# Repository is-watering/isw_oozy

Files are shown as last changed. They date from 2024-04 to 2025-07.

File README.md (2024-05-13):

# ISW-OOZY
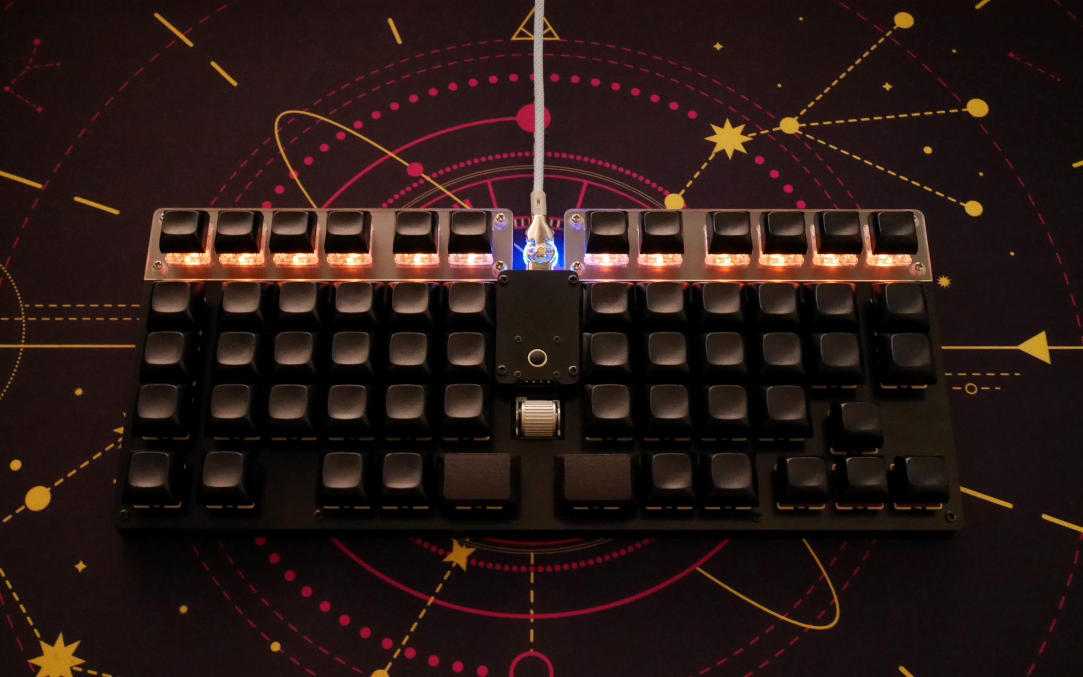
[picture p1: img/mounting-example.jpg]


ISW-OOZY is an orthoish keyboard with offset clusters.

[Build guide](doc/buildguide.md)

## Dependencies (KiCad)
* [is-watering/isw-kbd-lib](https://github.com/is-watering/isw-kbd-lib)
* [Salicylic-acid3/KiCAD_FootPrint](https://github.com/Salicylic-acid3/KiCAD_FootPrint)
* [koktoh/BrownSugar_KBD_KiCad_Library](https://github.com/koktoh/BrownSugar_KBD_KiCad_Library)

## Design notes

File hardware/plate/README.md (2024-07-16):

## Recommended format
Name                        |Material |Thickness      |Notes
----------------------------|---------|---------------|-----
Switch plate A              |-        |1.6mm or 2.0mm |
Switch plate B              |-        |1.6mm or 2.0mm |
Bottom plate                |-        |1.2mm - 2.0mm  |
Cover plate for AZ1UBALL    |FR4      |1.0mm - 1.2mm  |
Cover plate for StickPointV |-        |1.6mm or 2.0mm |

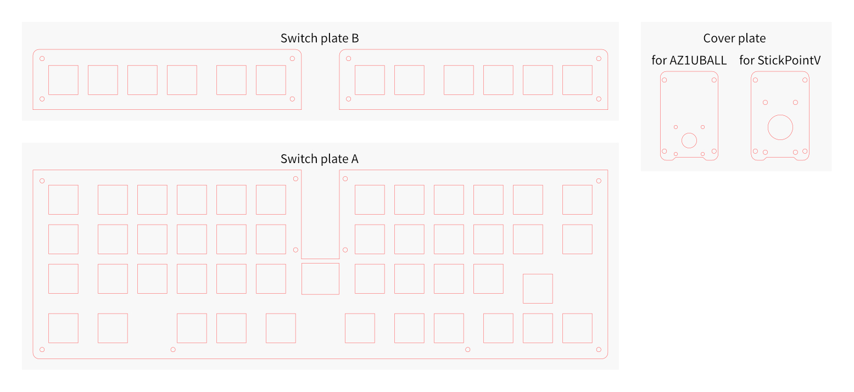
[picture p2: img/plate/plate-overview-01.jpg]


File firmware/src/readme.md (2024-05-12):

# isw_oozy

isw_oozy

*A short description of the keyboard/project*

* Keyboard Maintainer: [is_watering](https://github.com/is_watering)
* Hardware Supported: *The PCBs, controllers supported*
* Hardware Availability: *Links to where you can find this hardware*

Make example for this keyboard (after setting up your build environment):

    make isw_oozy:default

Flashing example for this keyboard:

    make isw_oozy:default:flash

See the [build environment setup](https://docs.qmk.fm/#/getting_started_build_tools) and the [make instructions](https://docs.qmk.fm/#/getting_started_make_guide) for more information. Brand new to QMK? Start with our [Complete Newbs Guide](https://docs.qmk.fm/#/newbs).

## Bootloader

Enter the bootloader in 3 ways:

* **Bootmagic reset**: Hold down the key at (0,0) in the matrix (usually the top left key or Escape) and plug in the keyboard
* **Physical reset button**: Briefly press the button on the back of the PCB - some may have pads you must short instead
* **Keycode in layout**: Press the key mapped to `QK_BOOT` if it is available

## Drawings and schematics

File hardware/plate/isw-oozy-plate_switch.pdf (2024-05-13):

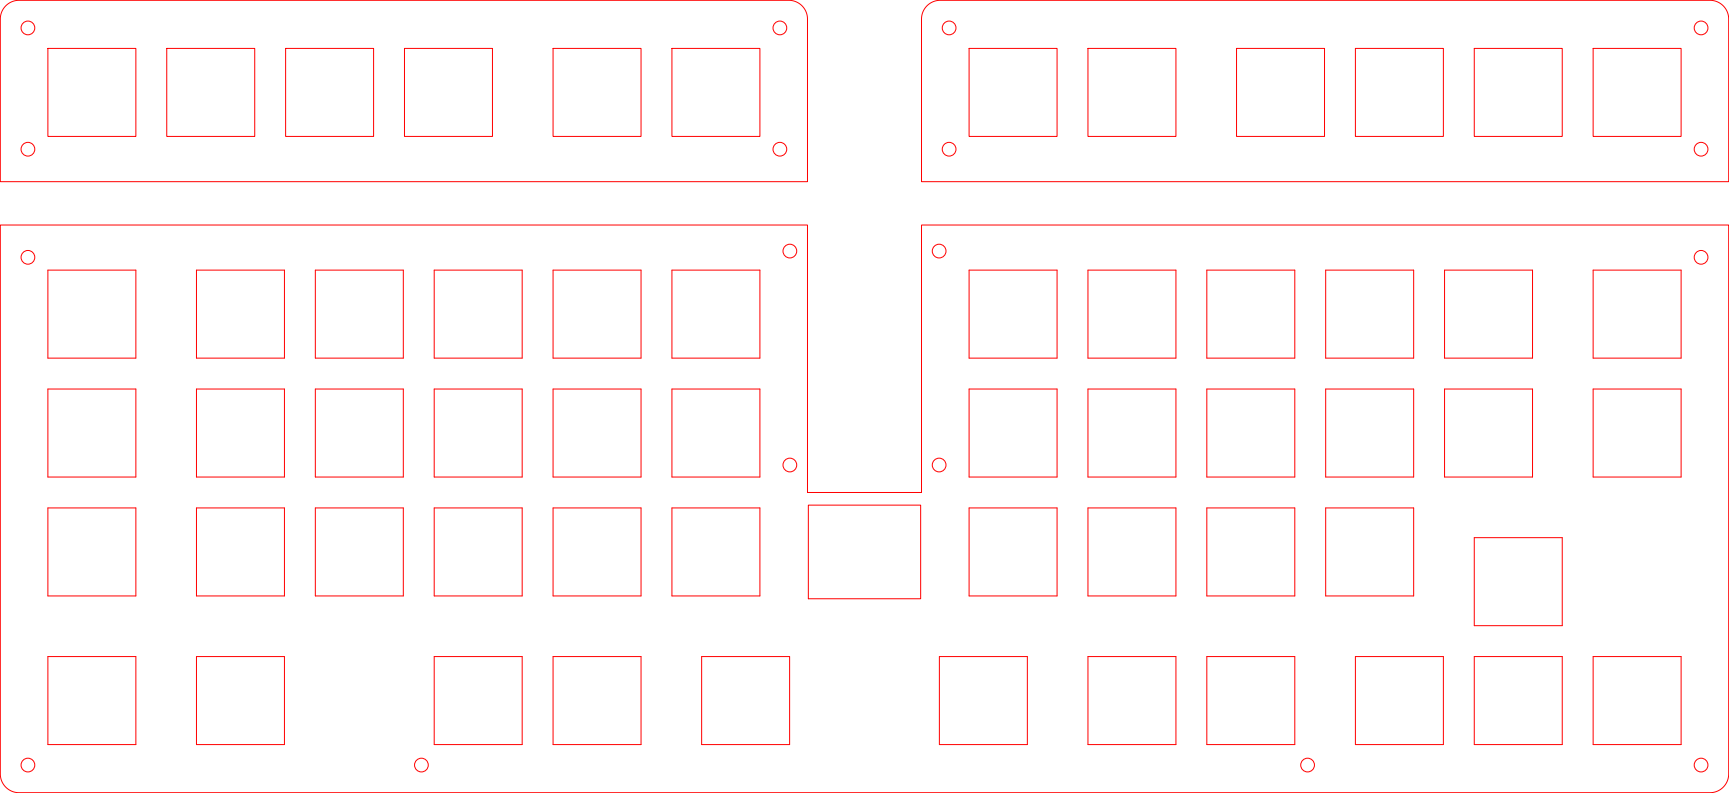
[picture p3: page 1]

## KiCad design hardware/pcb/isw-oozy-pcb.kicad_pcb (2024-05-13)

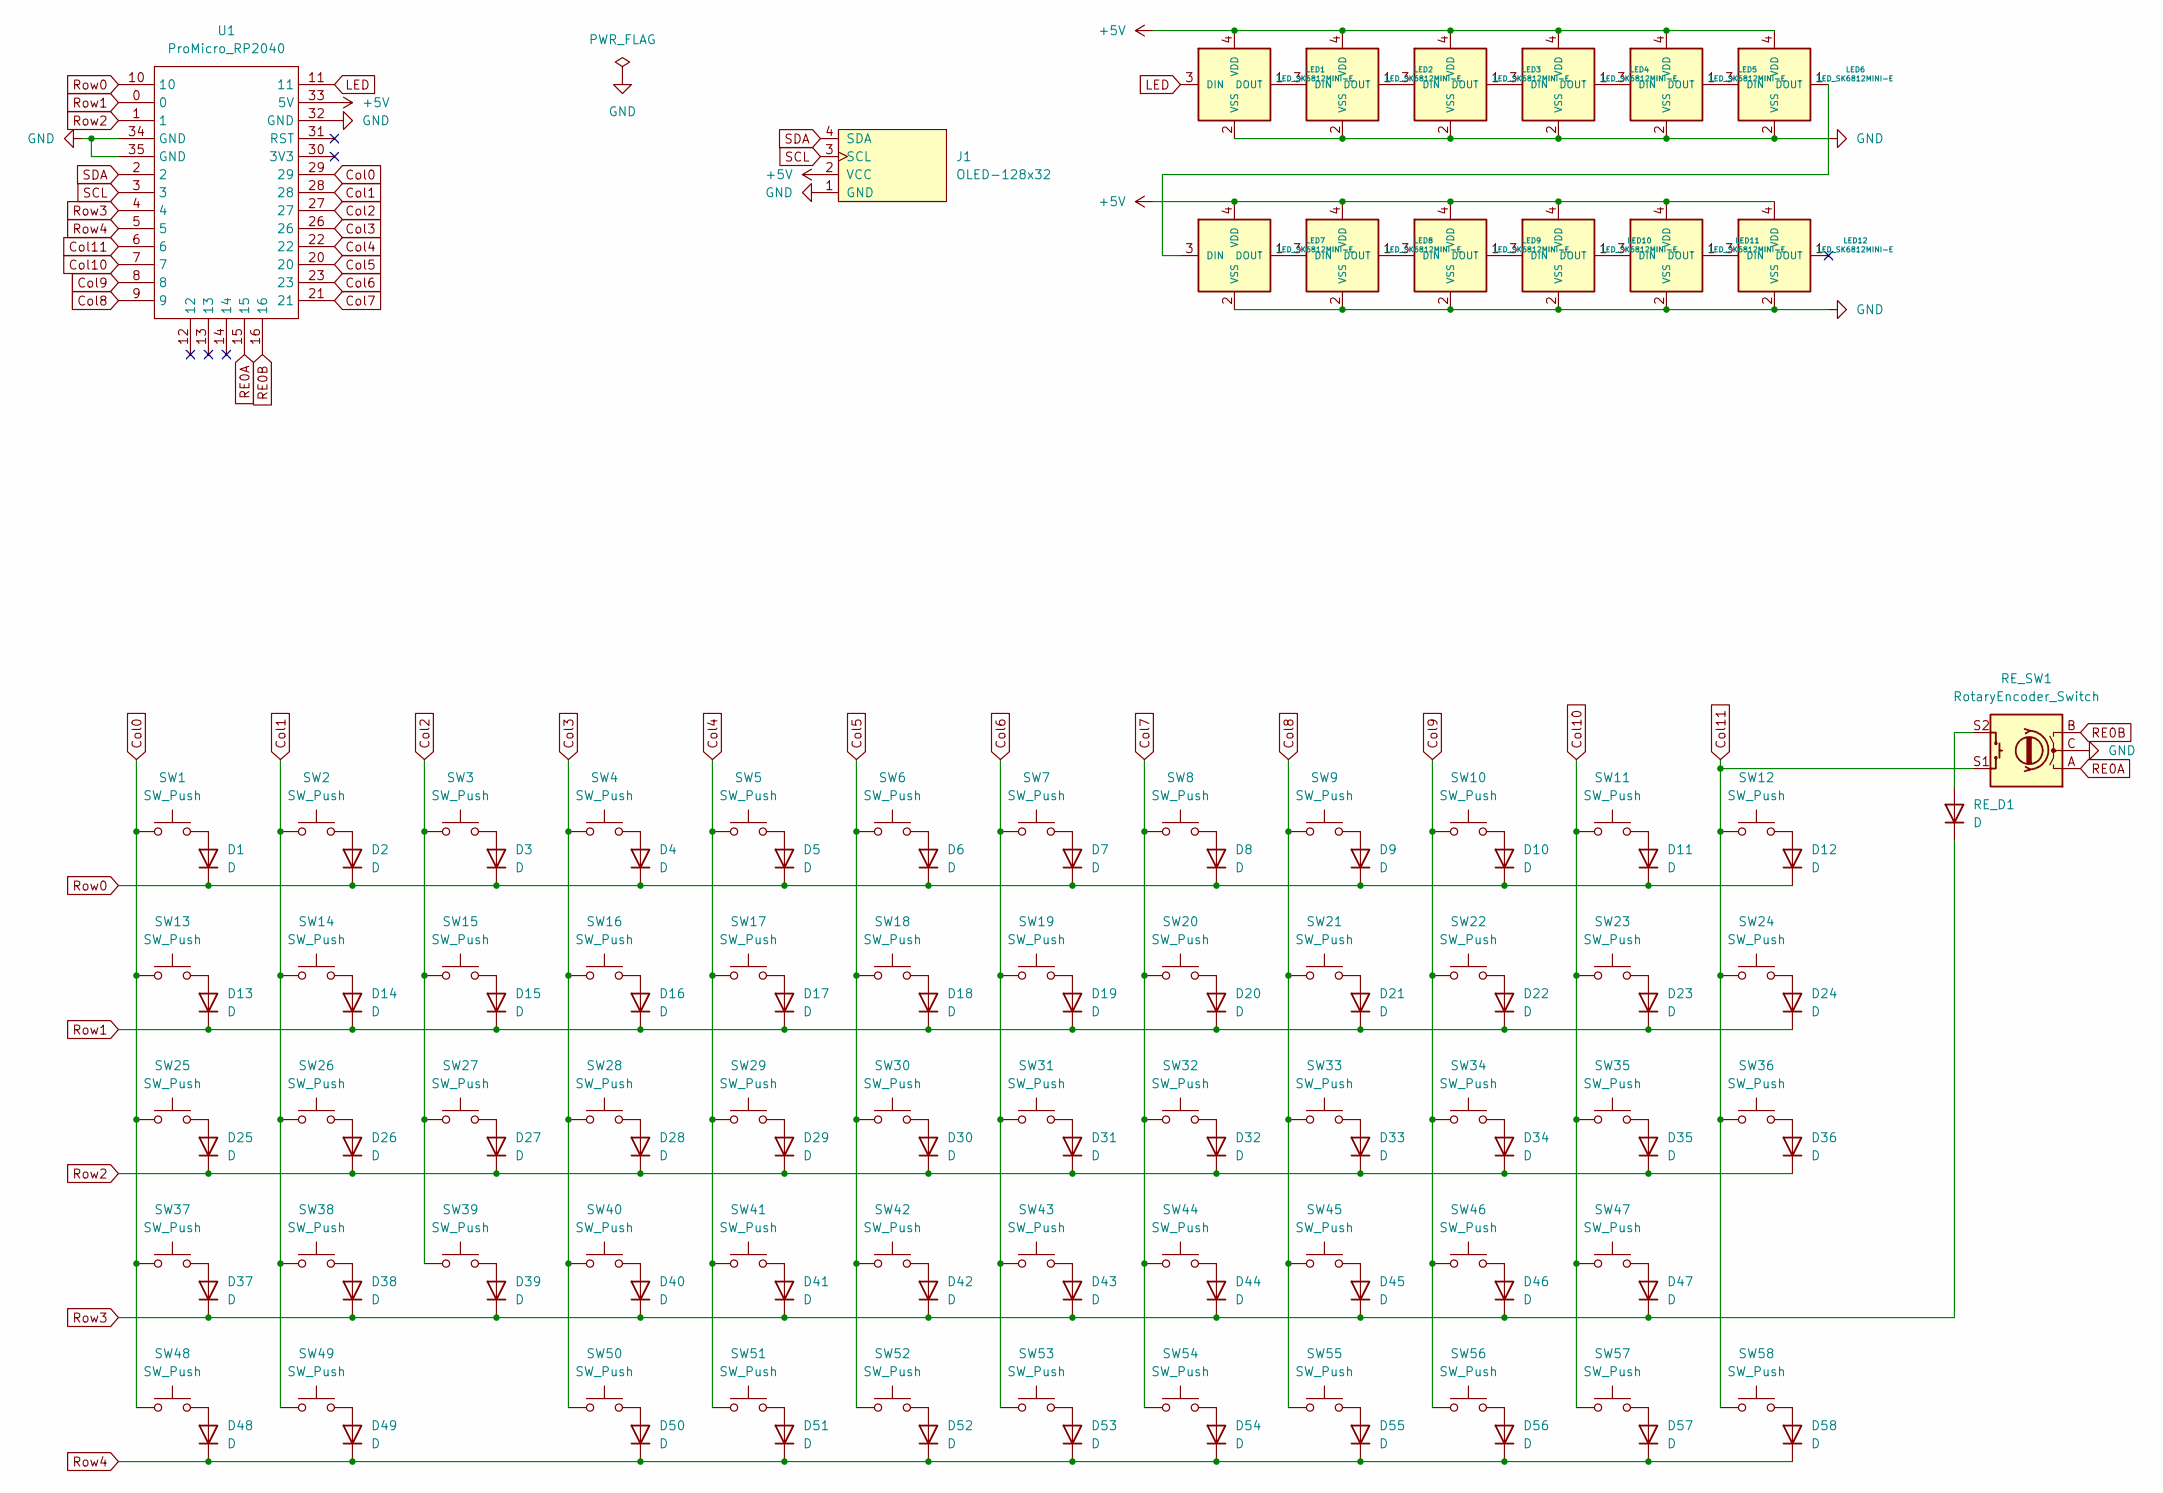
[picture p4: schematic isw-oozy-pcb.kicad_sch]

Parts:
D1, D2, D3, D4, D5, D6, D7, D8, D9, D10, D11, D12, D13, D14, D15, D16, D17, D18, D19, D20, D21, D22, D23, D24, D25, D26, D27, D28, D29, D30, D31, D32, D33, D34, D35, D36, D37, D38, D39, D40, D41, D42, D43, D44, D45, D46, D47, D48, D49, D50, D51, D52, D53, D54, D55, D56, D57, D58: D; Diode_TH_SMD
J1: OLED-128x32; AZ1UBALL
LED1, LED2, LED3, LED4, LED5, LED6, LED7, LED8, LED9, LED10, LED11, LED12: LED_SK6812MINI-E; LED_SK6812MINI-E_BL
RE_D1: D; Diode_TH_SMD
RE_SW1: RotaryEncoder_Switch; RotaryEncoder_EVQWGD001
SW1, SW2, SW3, SW4, SW5, SW6, SW7, SW8, SW9, SW10, SW11, SW12, SW13, SW14, SW15, SW16, SW17, SW18, SW19, SW20, SW21, SW22, SW23, SW24, SW25, SW26, SW27, SW28, SW29, SW30, SW31, SW32, SW33, SW34, SW35, SW36, SW37, SW38, SW39, SW40, SW41, SW42, SW43, SW44, SW45, SW46, SW47, SW48, SW49, SW50, SW51, SW52, SW53, SW54, SW55, SW56, SW57, SW58: SW_Push; CherryMX_Hotswap_1u
U1: ProMicro_RP2040

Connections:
+5V: J1.2 (VCC), LED1.4 (VDD), LED2.4 (VDD), LED3.4 (VDD), LED4.4 (VDD), LED5.4 (VDD), LED6.4 (VDD), LED7.4 (VDD), LED8.4 (VDD), LED9.4 (VDD), LED10.4 (VDD), LED11.4 (VDD), LED12.4 (VDD), U1.33 (5V)
Col0: SW1.1, SW13.1, SW25.1, SW37.1, SW48.1, U1.29
Col1: SW2.1, SW14.1, SW26.1, SW38.1, SW49.1, U1.28
Col2: SW3.1, SW15.1, SW27.1, SW39.1, U1.27
Col3: SW4.1, SW16.1, SW28.1, SW40.1, SW50.1, U1.26
Col4: SW5.1, SW17.1, SW29.1, SW41.1, SW51.1, U1.22
Col5: SW6.1, SW18.1, SW30.1, SW42.1, SW52.1, U1.20
Col6: SW7.1, SW19.1, SW31.1, SW43.1, SW53.1, U1.23
Col7: SW8.1, SW20.1, SW32.1, SW44.1, SW54.1, U1.21
Col8: SW9.1, SW21.1, SW33.1, SW45.1, SW55.1, U1.9
Col9: SW10.1, SW22.1, SW34.1, SW46.1, SW56.1, U1.8
Col10: SW11.1, SW23.1, SW35.1, SW47.1, SW57.1, U1.7
Col11: RE_SW1.S1, SW12.1, SW24.1, SW36.1, SW58.1, U1.6
LED: LED1.3 (DIN), U1.11
unnamed: D1.2 (A), SW1.2
unnamed: D2.2 (A), SW2.2
unnamed: D3.2 (A), SW3.2
unnamed: D4.2 (A), SW4.2
unnamed: D5.2 (A), SW5.2
unnamed: D6.2 (A), SW6.2
unnamed: D7.2 (A), SW7.2
unnamed: D8.2 (A), SW8.2
unnamed: D9.2 (A), SW9.2
unnamed: D10.2 (A), SW10.2
unnamed: D11.2 (A), SW11.2
unnamed: D12.2 (A), SW12.2
unnamed: D13.2 (A), SW13.2
unnamed: D14.2 (A), SW14.2
unnamed: D15.2 (A), SW15.2
unnamed: D16.2 (A), SW16.2
unnamed: D17.2 (A), SW17.2
unnamed: D18.2 (A), SW18.2
unnamed: D19.2 (A), SW19.2
unnamed: D20.2 (A), SW20.2
unnamed: D21.2 (A), SW21.2
unnamed: D22.2 (A), SW22.2
unnamed: D23.2 (A), SW23.2
unnamed: D24.2 (A), SW24.2
unnamed: D25.2 (A), SW25.2
unnamed: D26.2 (A), SW26.2
unnamed: D27.2 (A), SW27.2
unnamed: D28.2 (A), SW28.2
unnamed: D29.2 (A), SW29.2
unnamed: D30.2 (A), SW30.2
unnamed: D31.2 (A), SW31.2
unnamed: D32.2 (A), SW32.2
unnamed: D33.2 (A), SW33.2
unnamed: D34.2 (A), SW34.2
unnamed: D35.2 (A), SW35.2
unnamed: D36.2 (A), SW36.2
unnamed: D37.2 (A), SW37.2
unnamed: D38.2 (A), SW38.2
unnamed: D39.2 (A), SW39.2
unnamed: D40.2 (A), SW40.2
unnamed: D41.2 (A), SW41.2
unnamed: D42.2 (A), SW42.2
unnamed: D43.2 (A), SW43.2
unnamed: D44.2 (A), SW44.2
unnamed: D45.2 (A), SW45.2
unnamed: D46.2 (A), SW46.2
unnamed: D47.2 (A), SW47.2
unnamed: D48.2 (A), SW48.2
unnamed: D49.2 (A), SW49.2
unnamed: D50.2 (A), SW50.2
unnamed: D51.2 (A), SW51.2
unnamed: D52.2 (A), SW52.2
unnamed: D53.2 (A), SW53.2
unnamed: D54.2 (A), SW54.2
unnamed: D55.2 (A), SW55.2
unnamed: D56.2 (A), SW56.2
unnamed: D57.2 (A), SW57.2
unnamed: D58.2 (A), SW58.2
unnamed: LED1.1 (DOUT), LED2.3 (DIN)
unnamed: LED2.1 (DOUT), LED3.3 (DIN)
unnamed: LED3.1 (DOUT), LED4.3 (DIN)
unnamed: LED4.1 (DOUT), LED5.3 (DIN)
unnamed: LED5.1 (DOUT), LED6.3 (DIN)
unnamed: LED7.1 (DOUT), LED8.3 (DIN)
unnamed: LED8.1 (DOUT), LED9.3 (DIN)
unnamed: LED9.1 (DOUT), LED10.3 (DIN)
unnamed: LED10.1 (DOUT), LED11.3 (DIN)
unnamed: LED11.1 (DOUT), LED12.3 (DIN)
unnamed: RE_D1.2 (A), RE_SW1.S2
RE0A: RE_SW1.A, U1.15
RE0B: RE_SW1.B, U1.16
Row0: D1.1 (K), D2.1 (K), D3.1 (K), D4.1 (K), D5.1 (K), D6.1 (K), D7.1 (K), D8.1 (K), D9.1 (K), D10.1 (K), D11.1 (K), D12.1 (K), U1.10
Row1: D13.1 (K), D14.1 (K), D15.1 (K), D16.1 (K), D17.1 (K), D18.1 (K), D19.1 (K), D20.1 (K), D21.1 (K), D22.1 (K), D23.1 (K), D24.1 (K), U1.0
Row2: D25.1 (K), D26.1 (K), D27.1 (K), D28.1 (K), D29.1 (K), D30.1 (K), D31.1 (K), D32.1 (K), D33.1 (K), D34.1 (K), D35.1 (K), D36.1 (K), U1.1
Row3: D37.1 (K), D38.1 (K), D39.1 (K), D40.1 (K), D41.1 (K), D42.1 (K), D43.1 (K), D44.1 (K), D45.1 (K), D46.1 (K), D47.1 (K), RE_D1.1 (K), U1.4
Row4: D48.1 (K), D49.1 (K), D50.1 (K), D51.1 (K), D52.1 (K), D53.1 (K), D54.1 (K), D55.1 (K), D56.1 (K), D57.1 (K), D58.1 (K), U1.5
SCL: J1.3 (SCL), U1.3
SDA: J1.4 (SDA), U1.2

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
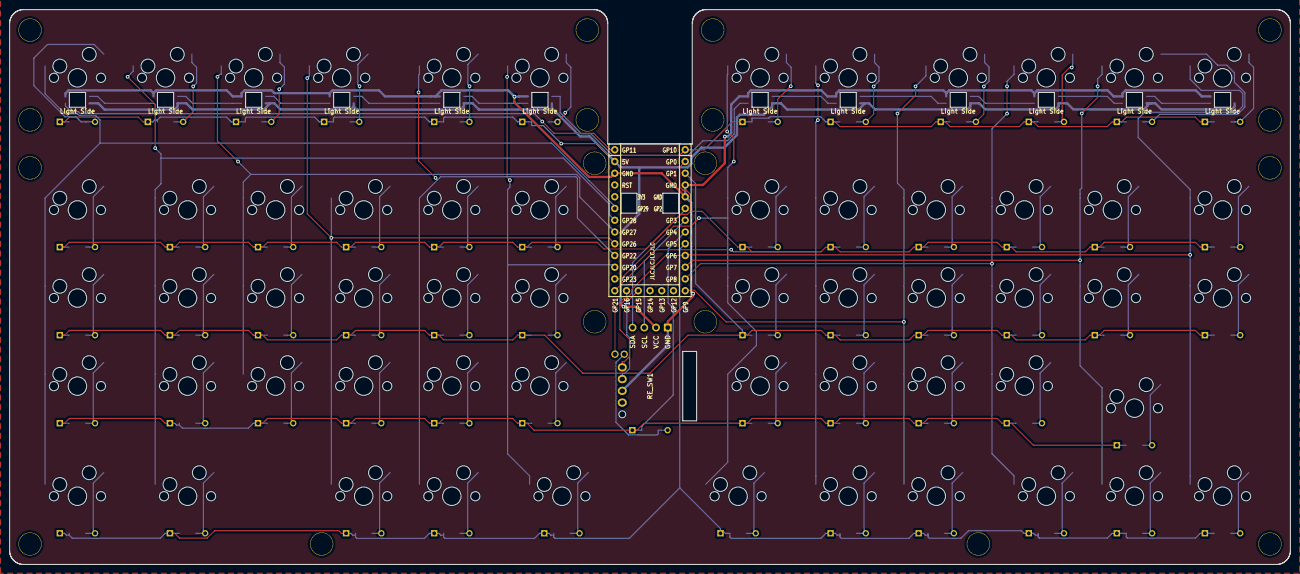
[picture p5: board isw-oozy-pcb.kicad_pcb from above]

Board: 2 copper layers, 277.0 x 120.0 mm, 150 parts (0 on the bottom side), 94 nets.

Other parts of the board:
Ref01: Val01; m2_Spacer_Hole
Ref02: Val02; m2_Spacer_Hole
Ref03: Val03; m2_Spacer_Hole
Ref04: Val04; m2_Spacer_Hole
Ref05: Val05; m2_Spacer_Hole
Ref06: Val06; m2_Spacer_Hole
Ref07: Val07; m2_Spacer_Hole
Ref08: Val08; m2_Spacer_Hole
Ref09: Val09; m2_Spacer_Hole
Ref10: Val10; m2_Spacer_Hole
Ref11: Val11; m2_Spacer_Hole
Ref12: Val12; m2_Spacer_Hole
Ref13: Val13; m2_Spacer_Hole
Ref14: Val14; m2_Spacer_Hole
Ref15: Val15; m2_Spacer_Hole
Ref16: Val16; m2_Spacer_Hole
Ref17: Val17; m2_Spacer_Hole
Ref18: Val18; m2_Spacer_Hole

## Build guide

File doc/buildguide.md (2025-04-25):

# Build guide

## Parts
Name                     |Quantity |Notes
-------------------------|---------|-----
PCB                      |1        |[Here's the data](https://github.com/is-watering/isw_oozy/tree/main/hardware/pcb)
Switch plate A           |1        |[Here's the data](https://github.com/is-watering/isw_oozy/tree/main/hardware/plate)
Switch plate B_Left      |1        |[Here's the data](https://github.com/is-watering/isw_oozy/tree/main/hardware/plate)
Switch plate B_Right     |1        |[Here's the data](https://github.com/is-watering/isw_oozy/tree/main/hardware/plate)
Bottom plate             |1        |[Here's the data](https://github.com/is-watering/isw_oozy/tree/main/hardware/plate)
Cover plate              |1        |[Here's the data](https://github.com/is-watering/isw_oozy/tree/main/hardware/plate)
SK6812 MINI-E leds       |12       |
1N4148W diodes           |58       |
Kailh hotswap sockets    |58       |
ProMicro RP2040          |1        |[Aliexpress](https://www.aliexpress.com/item/1005006355650714.html)
M2x4mm screws            |32       |
M2x12mm screws           |4        |
M2x7mm spacers           |18       |[HIROSUGI NET](https://www.hirosugi-net.co.jp/shop/c/c10141012/)
M2x7mm Knurled spacers   |4        |[Aliexpress](https://www.aliexpress.com/item/1005002979083511.html)

### Optionally
Name |Quantity |Notes
-----|---------|-----
20P Low profile pinsocket |2    |Used to socket the ProMicro RP2040.<br>[AKIZUKI DENSHI](https://akizukidenshi.com/catalog/g/g103138/)
EVQWGD001 rotary encoder  |1    |[Aliexpress](https://www.aliexpress.com/item/32990950196.html), [TALPKEYBOARD](https://talpkeyboard.net/items/65cdb71207d2c4002b622ce0), [Yushakobo](https://shop.yushakobo.jp/products/3971)
1N4148W diodes            |1    |Used when EVQWGD001 is installed
AZ1UBALL                  |1    |Only one of this or StickPointV can be attached.<br>[Booth](https://booth.pm/ja/items/4202085)
StickPointV               |1    |Only one of this or AZ1UBALL can be attached.<br>Also, use those without glove socket mounts.<br>[Booth](https://booth.pm/ja/items/5404009)
FSS-41035-04 4P pinsocket |1    |Used when AZ1UBALL or StickPointV is installed.<br>[HIROSUGI NET](https://www.hirosugi-net.co.jp/shop/goods/goods.aspx?goods=24081), [Yushakobo](https://shop.yushakobo.jp/products/a1600ps-01-1)
PSS-410153-04 4P pinheader |1    |Used when AZ1UBALL or StickPointV is installed.<br>[HIROSUGI NET](https://www.hirosugi-net.co.jp/shop/g/g21243/), [Yushakobo](https://shop.yushakobo.jp/products/a1600ph-01-1)
M2x6mm Knurled spacers     |4        |Used when StickPointV is installed.<br>[Aliexpress](https://www.aliexpress.com/item/1005002979083511.html)
M2x10mm Knurled spacers    |4        |Used when StickPointV is installed.<br>[Aliexpress](https://www.aliexpress.com/item/1005002979083511.html)

## Build PCB

### [Leds](https://github.com/is-watering/isw-kbd-building-tips/blob/main/doc/en/soldering-sk6812mini-e.md)

### [Diodes](https://github.com/is-watering/isw-kbd-building-tips/blob/main/doc/en/soldering-1n4148w.md)

### [Hotswap sockets](https://github.com/is-watering/isw-kbd-building-tips/blob/main/doc/en/soldering-cpg151101s11.md)

### ProMicro RP2040
It is recommended to check whether the firmware can be written to the microcontroller in advance.
* [Remap](https://remap-keys.app/catalog/9zuSGbfh9XDFOtDtdAaT)
* [Soure code](https://github.com/is-watering/isw_oozy/tree/main/firmware)

When using a low profile pinsocket, cut the pinsocket to match the shape of the through-hole and solder it at the point marked in red.  
[Learn more about microcontroller socketing using low profile pinsocket](https://github.com/is-watering/isw-kbd-building-tips/blob/main/doc/en/microcontroller-socketing_low-profile-pinsocket.md)

When directly soldering a pin header, cut the pin header to match the shape of the through-hole and solder it to the ProMicro RP2040 at the point marked in red.  
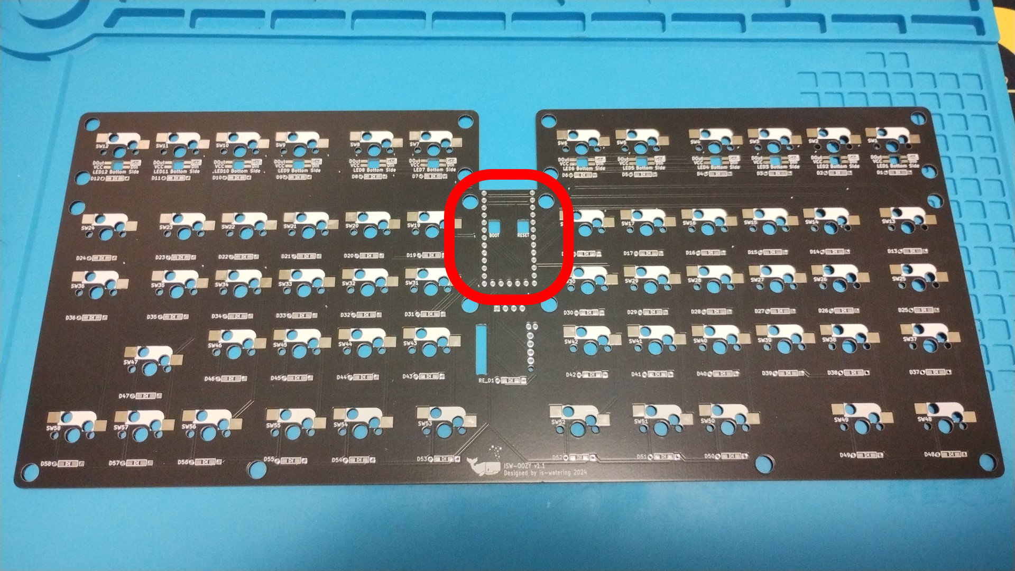
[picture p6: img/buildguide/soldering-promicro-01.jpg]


## Build Case
Use a 4mm screw to secure the 7mm spacer. However, use a 12mm screw to secure the red marked areas.  
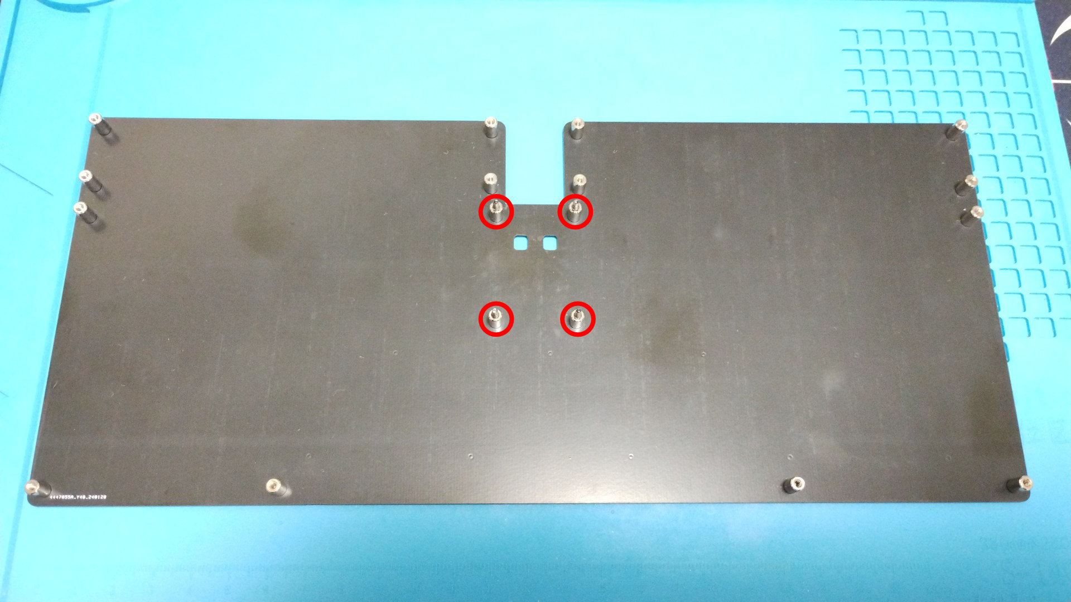
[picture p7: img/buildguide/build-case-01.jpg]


Place the PCB on the bottom plate.  
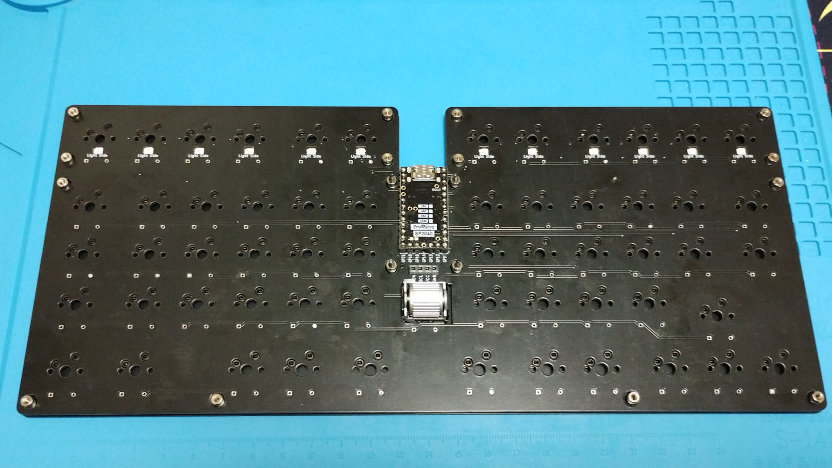
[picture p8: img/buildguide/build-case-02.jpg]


Place switch plate A on the PCB. It is easier to align the key switches if they are attached to the four corners.  
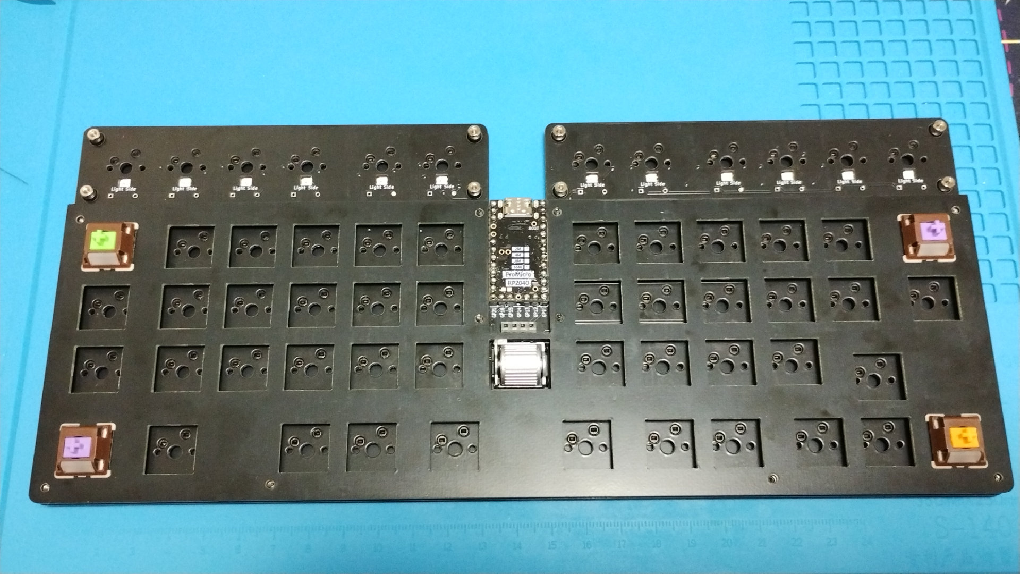
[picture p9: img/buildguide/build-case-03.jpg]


Place switch plate B on the PCB. It is easier to align the key switches if they are attached to both ends.  
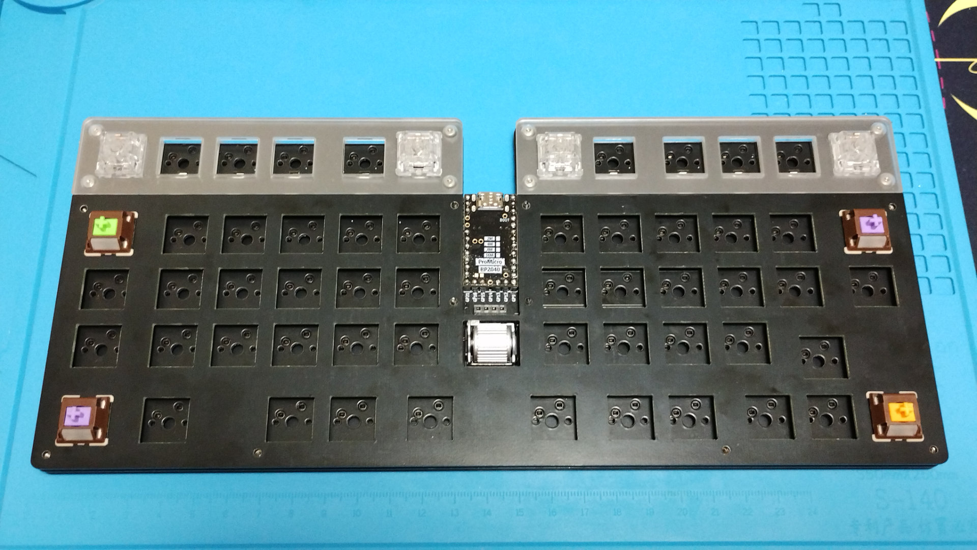
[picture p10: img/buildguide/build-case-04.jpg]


Use a 4mm screw to secure the switch plate.Fix the switch plate using a 4mm screw.  
Also, attach the 7mm Knurled spacer at the point marked in red.  
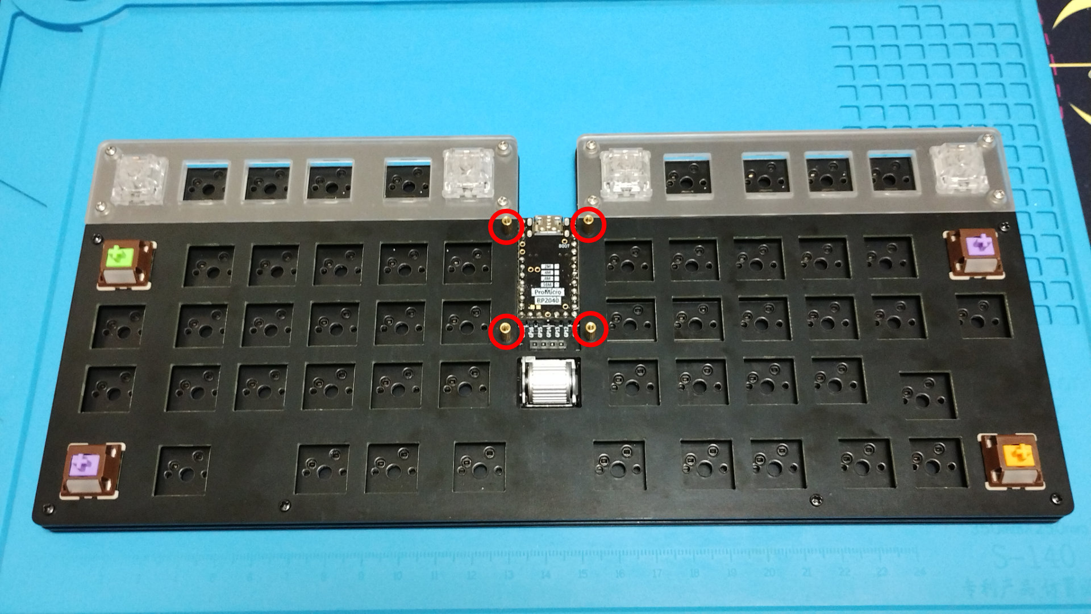
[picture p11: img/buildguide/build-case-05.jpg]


Fix the cover plate with a 4mm screw.  
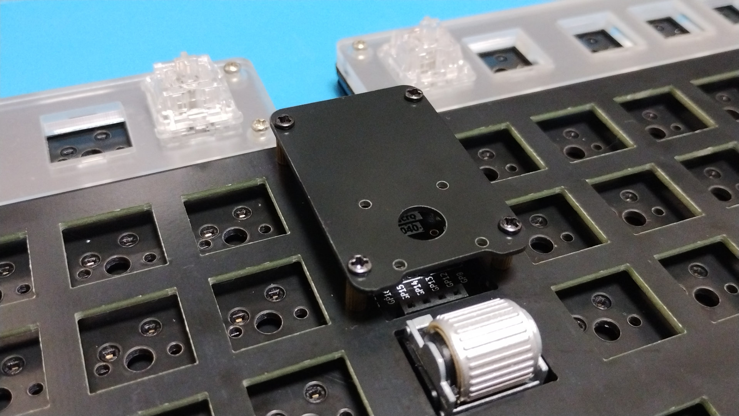
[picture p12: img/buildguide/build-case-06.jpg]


Attach a key switch and key cap of your choice to complete the process!  
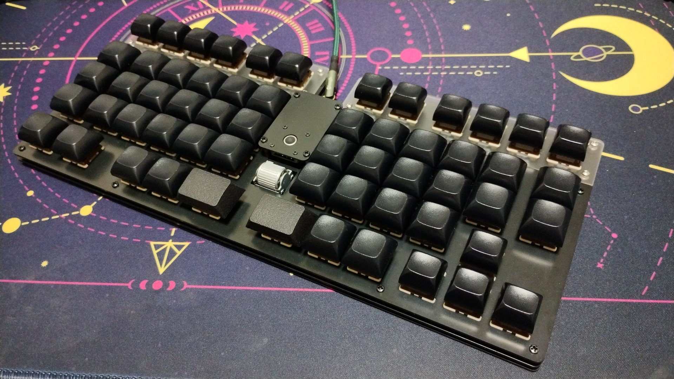
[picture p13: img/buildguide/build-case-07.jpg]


Congratulations on the completion!  
Please be proud of it on social networking sites!  
`#isw_kbd`

## Build Optionally
### [EVQWGD001 rotary encoder](https://github.com/is-watering/isw-kbd-building-tips/blob/main/doc/en/soldering-evqwgd001.md)

### AZ1UBALL
[Please solder the 4P pinsocket to the PCB in advance.](https://github.com/is-watering/isw-kbd-building-tips/blob/main/doc/en/soldering-4p-pinsocket.md)

Mount AZ1UBALL in 4P pinsocket.  
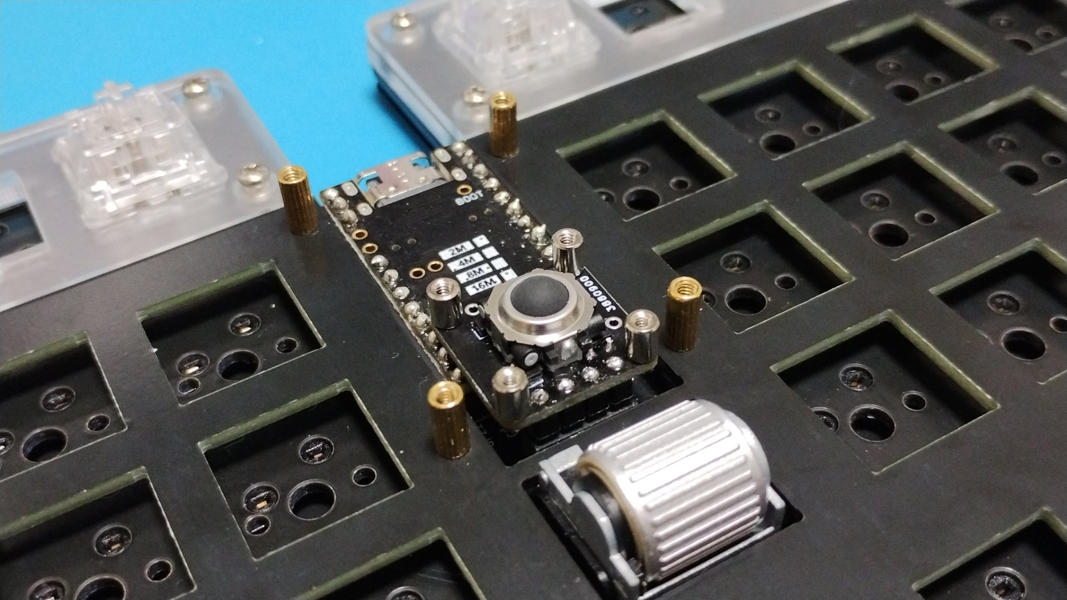
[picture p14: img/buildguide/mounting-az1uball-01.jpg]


Attach the cover plate for AZ1UBALL with screws.
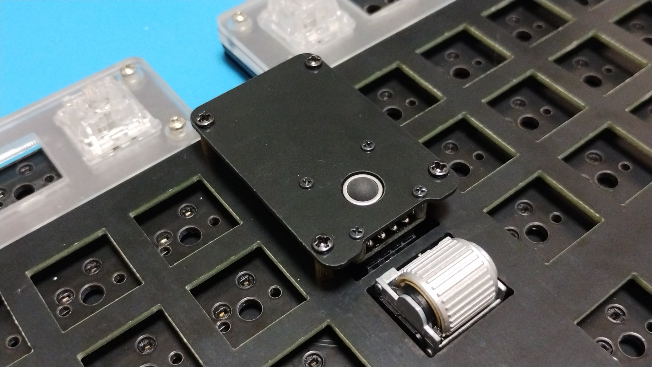
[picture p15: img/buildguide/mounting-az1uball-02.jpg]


### StickPointV
[Please solder the 4P pinsocket to the PCB in advance.](https://github.com/is-watering/isw-kbd-building-tips/blob/main/doc/en/soldering-4p-pinsocket.md)

Replace the spacer supplied with the StickPointV with a 6mm Knurled spacer and the 7mm Knurled spacer on the keyboard case with a 10mm Knurled spacer.  
Then mount the StickPointV in the 4P pinsocket.  
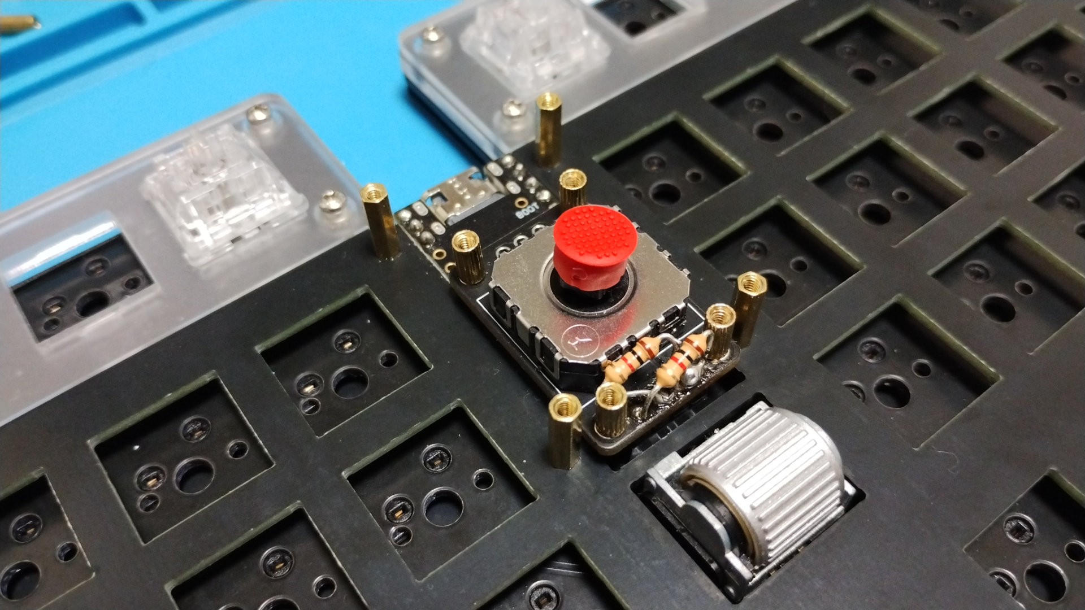
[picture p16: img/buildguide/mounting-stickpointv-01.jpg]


Attach the cover plate for StickPointV with screws.
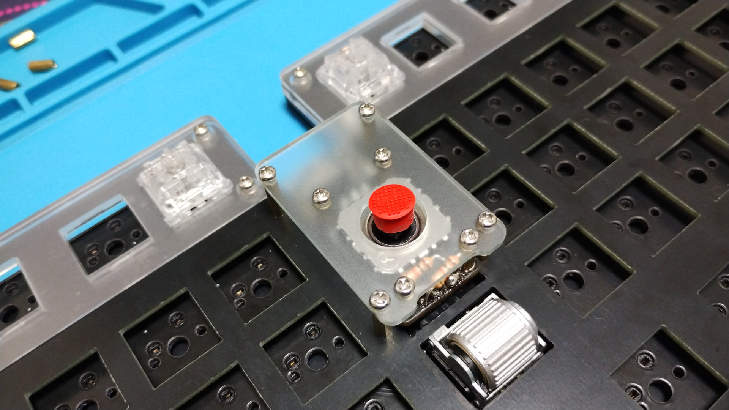
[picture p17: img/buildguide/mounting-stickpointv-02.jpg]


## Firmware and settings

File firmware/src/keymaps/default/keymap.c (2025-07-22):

/* SPDX-License-Identifier: GPL-2.0-or-later */

#include QMK_KEYBOARD_H

const uint16_t PROGMEM keymaps[][MATRIX_ROWS][MATRIX_COLS] = {
	[0] = LAYOUT(
		KC_F1,   KC_F2,      KC_F3,              KC_F4,   KC_F5,                KC_F6,           KC_F7,        KC_F8,                 KC_F9,                 KC_F10,     KC_F11,                KC_F12,
		KC_TAB,  LT(1,KC_Q), KC_W,               KC_E,    KC_R,                 KC_T,            KC_Y,         KC_U,                  KC_I,                  KC_O,       KC_P,                  KC_BSPC,
		KC_LSFT, KC_A,       KC_S,               KC_D,    KC_F,                 KC_G,            KC_H,         KC_J,                  KC_K,                  LT(2,KC_L), MT(MOD_RSFT, KC_SCLN), MT(MOD_RSFT, KC_QUOT),
		KC_LCTL, KC_Z,       MT(MOD_LSFT, KC_X), KC_C,    KC_V,                 KC_B,            KC_N,         KC_M,                  MT(MOD_RGUI, KC_COMM), KC_DOT,     KC_UP,                 KC_BTN3,
		MO(1),   KC_LGUI,                        KC_LALT, MT(MOD_LCTL, KC_TAB), LT(1,KC_SPC),    LT(2,KC_ENT), MT(MOD_RALT, KC_SLSH), KC_RCTL,               KC_LEFT,    KC_DOWN,               KC_RGHT
	),

	[1] = LAYOUT(
		XXXXXXX, XXXXXXX,    XXXXXXX, XXXXXXX, XXXXXXX, XXXXXXX,         XXXXXXX,       XXXXXXX,    XXXXXXX,    XXXXXXX,    XXXXXXX, XXXXXXX,
		XXXXXXX, KC_SLSH,    KC_7,    KC_8,    KC_9,    KC_MINS,         RSFT(KC_MINS), RSFT(KC_2), RSFT(KC_3), KC_LBRC,    KC_RBRC, XXXXXXX,
		XXXXXXX, RSFT(KC_8), KC_4,    KC_5,    KC_6,    RSFT(KC_EQL),    RSFT(KC_6),    RSFT(KC_5), RSFT(KC_7), RSFT(KC_4), KC_QUOT, XXXXXXX,
		XXXXXXX, KC_ESC,     KC_1,    KC_2,    KC_3,    KC_EQL,          RSFT(KC_1),    XXXXXXX,    RSFT(KC_9), RSFT(KC_0), KC_PGUP, XXXXXXX,
		XXXXXXX, XXXXXXX,             KC_0,    KC_DOT,  KC_SPC,          MO(3),         KC_BSLS,    KC_BSPC,    KC_HOME,    KC_PGDN, KC_END
	),

	[2] = LAYOUT(
		XXXXXXX, XXXXXXX, XXXXXXX, XXXXXXX, XXXXXXX, XXXXXXX,    XXXXXXX,      XXXXXXX,       XXXXXXX,    XXXXXXX,       XXXXXXX,       XXXXXXX,
		XXXXXXX, XXXXXXX, KC_F1,   KC_F2,   KC_F3,   KC_F4,      KC_BTN1,      KC_BTN3,       KC_BTN2,    RSFT(KC_LBRC), RSFT(KC_RBRC), KC_DEL,
		XXXXXXX, XXXXXXX, KC_F5,   KC_F6,   KC_F7,   KC_F8,      KC_LEFT,      KC_DOWN,       KC_UP,      KC_RIGHT,      RSFT(KC_QUOT), XXXXXXX,
		XXXXXXX, KC_GRV,  KC_F9,   KC_F10,  KC_F11,  KC_F12,     KC_HOME,      KC_PGDN,       KC_PGUP,    KC_END,	       KC_PGUP,       XXXXXXX,
		XXXXXXX, XXXXXXX,          XXXXXXX, XXXXXXX, XXXXXXX,    RSFT(KC_INS), RSFT(KC_BSLS), KC_DEL,     KC_HOME,       KC_PGDN,       KC_END
	),

	[3] = LAYOUT(
		XXXXXXX, XXXXXXX, XXXXXXX,  XXXXXXX, XXXXXXX, XXXXXXX,   XXXXXXX, XXXXXXX,       XXXXXXX, XXXXXXX, XXXXXXX, XXXXXXX,
		KC_CAPS, RGB_TOG, RGB_VAI,  RGB_VAD, XXXXXXX, XXXXXXX,   XXXXXXX, RCTL(KC_PSCR), KC_PSCR, XXXXXXX, XXXXXXX, QK_BOOT,
		XXXXXXX, RGB_HUI, RGB_HUD,  RGB_SAI, RGB_SAD, XXXXXXX,   XXXXXXX, XXXXXXX,       XXXXXXX, XXXXXXX, XXXXXXX, XXXXXXX,
		XXXXXXX, RGB_MOD, RGB_RMOD, XXXXXXX, XXXXXXX, XXXXXXX,   XXXXXXX, XXXXXXX,       XXXXXXX, XXXXXXX, XXXXXXX, XXXXXXX,
		XXXXXXX, XXXXXXX,           XXXXXXX, XXXXXXX, XXXXXXX,   XXXXXXX, XXXXXXX,       XXXXXXX, XXXXXXX, XXXXXXX, XXXXXXX
	),
};


/* `ENCODER_MAP_ENABLE = yes` must be added to the rules.mk at the KEYMAP level. See QMK docs. */
/* Remove the following code if you do not enable it in your keymap (e.g. default keymap). */
#if defined(ENCODER_MAP_ENABLE)
const uint16_t PROGMEM encoder_map[][NUM_ENCODERS][2] = {
	[0] = { ENCODER_CCW_CW(KC_WH_D, KC_WH_U) },
	[1] = { ENCODER_CCW_CW(RGB_VAD, RGB_VAI) },
	[2] = { ENCODER_CCW_CW(KC_NO, KC_NO) },
	[3] = { ENCODER_CCW_CW(KC_NO, KC_NO) }
};
#endif
